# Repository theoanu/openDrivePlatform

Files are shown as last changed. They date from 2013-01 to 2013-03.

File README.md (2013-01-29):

openDrivePlatform
=================

Open-source Hardware/Software motor drive platform from which other more application-specific platforms may be derived.  See below for FUTURE release features.

Connectivity
=================
 - USB (virtual COM port) control
 - I2C control
 - Remote Control (RC) pulse
 - Fast RC pulse control
 - Analog control

Motor types supported
=================
 - Direct Current (DC)
 - Brushless DC (BLDC) - sensored
 - BLDC - sensorless
 - Permanent Magnet Synchronous Motor (PMSM)

Application types supported
=================
 - RC traction applications (wheels, belts, etc.)
 - RC propeller applications
 - Servo applications

Fun features supported
=================
 - Command-line interface using USB
 - Closed-loop Current/torque control
 - Closed-loop Speed control
 - Closed-loop power control
 - Regenerative braking

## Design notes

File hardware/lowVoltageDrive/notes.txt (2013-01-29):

Future revisions:
CAN transceiver: SN65HVD232DR

Current revision:

- In order to increase the gain of the opamp to 10:
 - Change R25, R26 to 10k

- In order to increase the resolution of the ADCs:
 - Change R7, R10, R12, and R14 to 3.3k

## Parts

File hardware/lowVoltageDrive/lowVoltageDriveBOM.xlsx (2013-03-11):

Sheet: lowVoltageDrive
Reference | Value | Manufacturer | Man. Part Number
C1 | 0.47uF 50V | Taiyo Yuden | UMK107B7474KA-TR
C2 | 0.47uF 50V | Taiyo Yuden | UMK107B7474KA-TR
C3 | 1nF 50V | Murata Electronics North America | GRM188R71H102KA01D
C4 | 1nF 50V | Murata Electronics North America | GRM188R71H102KA01D
C5 | 8pF 50V | TDK Corporation | C1608C0G1H080C
C6 | 8pF 50V | TDK Corporation | C1608C0G1H080C
C7 | 1nF 50V | Murata Electronics North America | GRM188R71H102KA01D
C8 | 1nF 50V | Murata Electronics North America | GRM188R71H102KA01D
C9 | 1nF 50V | Murata Electronics North America | GRM188R71H102KA01D
C10 | 0.47uF 50V | Taiyo Yuden | UMK107B7474KA-TR
C11 | 1nF 50V | Murata Electronics North America | GRM188R71H102KA01D
C12 | 0.47uF 50V | Taiyo Yuden | UMK107B7474KA-TR
C13 | 0.47uF 50V | Taiyo Yuden | UMK107B7474KA-TR
C14 | 0.47uF 50V | Taiyo Yuden | UMK107B7474KA-TR
C15 | 0.47uF 50V | Taiyo Yuden | UMK107B7474KA-TR
C16 | 220uF 6.3V | Panasonic Electronic Components | EEE-0JA221WP
C17 | 47uF 25V | Kemet | EEV476M025A9GAA
C18 | 47uF 25V | Kemet | EEV476M025A9GAA
C19 | 0.47uF 50V | Taiyo Yuden | UMK107B7474KA-TR
C20 | 0.47uF 50V | Taiyo Yuden | UMK107B7474KA-TR
C21 | 0.47uF 50V | Taiyo Yuden | UMK107B7474KA-TR
C22 | 0.47uF 50V | Taiyo Yuden | UMK107B7474KA-TR
C23 | 0.47uF 50V | Taiyo Yuden | UMK107B7474KA-TR
C24 | 0.47uF 50V | Taiyo Yuden | UMK107B7474KA-TR
D1 | DIODE | Micro Commercial Inc. | 1N4148WX-TP
D2 | DIODE | Micro Commercial Inc. | 1N4148WX-TP
D3 | DIODE | Micro Commercial Inc. | 1N4148WX-TP
D4 | DIODE | Micro Commercial Inc. | 1N4148WX-TP
J1 | CONN_5X2
J2 | CONN_5
J3 | CONN_5 | TE Connectivity | 5-1775444-5
J4 | CONN_5 | On Shore Technology Inc | OSTTC050162
J5 | CONN_6 | TE Connectivity | 5-1775444-6
Q1 | MOSFET_N_TO220 | Alpha & Omega Semiconductor | AOTF240L
Q2 | MOSFET_N_TO220 | Alpha & Omega Semiconductor | AOTF240L
Q3 | MOSFET_N_TO220 | Alpha & Omega Semiconductor | AOTF240L
Q4 | MOSFET_N_TO220 | Alpha & Omega Semiconductor | AOTF240L
Q5 | MOSFET_N_TO220 | Alpha & Omega Semiconductor | AOTF240L
Q6 | MOSFET_N_TO220 | Alpha & Omega Semiconductor | AOTF240L
R1 | 10.0k | Yageo | RC0603FR-0710KL
R2 | 1.0k | Yageo | RC0603FR-071KL
R3 | 10.0k | Yageo | RC0603FR-0710KL
R4 | 10.0k | Yageo | RC0603FR-0710KL
R5 | 10.0k | Yageo | RC0603FR-0710KL
R6 | 10.0k | Yageo | RC0603FR-0710KL
R7 | 1.5k | Yageo | RC0603FR-071K5L
R8 | 10.0k | Yageo | RC0603FR-0710KL
R9 | 10.0k | Yageo | RC0603FR-0710KL
R10 | 1.5k | Yageo | RC0603FR-071K5L
R11 | 10.0k | Yageo | RC0603FR-0710KL
R12 | 1.5k | Yageo | RC0603FR-071K5L
R13 | 10.0k | Yageo | RC0603FR-0710KL
R14 | 1.5k | Yageo | RC0603FR-071K5L
R15 | 1.0k | Yageo | RC0603FR-071KL
R16 | 1.0k | Yageo | RC0603FR-071KL
R17 | 1.0k | Yageo | RC0603FR-071KL
R18 | 1.0k | Yageo | RC0603FR-071KL
R19 | 1.5k | Yageo | RC0603FR-071K5L
R20 | 1.0k | Yageo | RC0603FR-071KL
R21 | 1.0k | Yageo | RC0603FR-071KL
R22 | 1.0k | Yageo | RC0603FR-071KL
R23 | 10.0k | Yageo | RC0603FR-0710KL
R24 | 1.0k | Yageo | RC0603FR-071KL
R25 | 1.0k | Yageo | RC0603FR-071KL
R26 | 1.0k | Yageo | RC0603FR-071KL
R27 | 33 | Yageo | RC0603JR-0733RL
R28 | 33 | Yageo | RC0603JR-0733RL
R29 | 33 | Yageo | RC0603JR-0733RL
R30 | 33 | Yageo | RC0603JR-0733RL
R31 | 33 | Yageo | RC0603JR-0733RL
R32 | 33 | Yageo | RC0603JR-0733RL
R33 | 10.0k | Yageo | RC0603FR-0710KL
R34 | 10.0k | Yageo | RC0603FR-0710KL
R35 | 1.0k | Yageo | RC0603FR-071KL
R36 | 1.0k | Yageo | RC0603FR-071KL
R37 | 0.01 | Vishay Dale | WSH2818R0100FEA
U1 | VREG_4 | ON Semiconductor | NCP1117LPST33T3G
U2 | STM32F103XX-48 | STMicroelectronics | STM32F103C4T6A
U3 | QUAD_OPAMP | STMicroelectronics | TS974IDT
U4 | MOSFET_DRIVER | International Rectifier | IR2301SPBF
U5 | MOSFET_DRIVER | International Rectifier | IR2301SPBF
U6 | MOSFET_DRIVER | International Rectifier | IR2301SPBF
X1 | CRYSTAL | NDK | NX5032GA 8MHZ AT-W

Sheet: Sheet1
Item | Qty | Reference | Value | Manufacturer | Man. Part Number | 10pc Price/part | 10pc Price | 1kpc Price/part | 1kpc Price
1 | 13 | C1,C2,C10,C12,C13,C14,C15,C19,C20,C21,C22,C23,C24 | 0.47uF 50V | Taiyo Yuden | UMK107B7474KA-TR | $0.0640 | $0.8320 | $0.0152 | $0.1976
2 | 6 | C3,C4,C7,C8,C9,C11 | 1nF 50V | Murata Electronics North America | GRM188R71H102KA01D | $0.0110 | $0.0660 | $0.0039 | $0.0235
3 | 2 | C5,C6 | 8pF 50V | TDK Corporation | C1608C0G1H080C | $0.0420 | $0.0840 | $0.0105 | $0.0210
4 | 1 | C16 | 220uF 6.3V | Panasonic Electronic Components | EEE-0JA221WP | $0.5500 | $0.5500 | $0.0992 | $0.0992
5 | 2 | C17,C18 | 47uF 25V | Kemet | EEV476M025A9GAA | $0.3050 | $0.6100 | $0.0783 | $0.1566
6 | 4 | D1,D2,D3,D4 | DIODE | Micro Commercial Inc. | 1N4148WX-TP | $0.1320 | $0.5280 | $0.0286 | $0.1144
7 | 1 | J1 | CONN_5X2 |  |  |  | $0.0000 |  | $0.0000
8 | 1 | J2 | CONN_5 |  |  |  | $0.0000 |  | $0.0000
9 | 1 | J3 | CONN_5 | TE Connectivity | 5-1775444-5 | $0.5710 | $0.5710 | $0.2857 | $0.2857
10 | 1 | J4 | CONN_5 | On Shore Technology Inc | OSTTC050162 | $0.6550 | $0.6550 | $0.4112 | $0.4112
11 | 1 | J5 | CONN_6 | TE Connectivity | 5-1775444-6 | $0.6820 | $0.6820 | $0.3411 | $0.3411
12 | 6 | Q1,Q2,Q3,Q4,Q5,Q6 | MOSFET_N_TO220 | Alpha & Omega Semiconductor | AOTF240L | $1.6200 | $9.7200 | $0.8424 | $5.0544
13 | 12 | R1,R3,R4,R5,R6,R8,R9,R11,R13,R23,R33,R34 | 10.0k | Yageo | RC0603FR-0710KL | $0.0063 | $0.0756 | $0.0015 | $0.0179
14 | 13 | R2,R15,R16,R17,R18,R20,R21,R22,R24,R25,R26,R35,R36 | 1.0k | Yageo | RC0603FR-071KL | $0.0063 | $0.0819 | $0.0015 | $0.0194
15 | 5 | R7,R10,R12,R14,R19 | 1.5k | Yageo | RC0603FR-071K5L | $0.0140 | $0.0700 | $0.0017 | $0.0086
16 | 6 | R27,R28,R29,R30,R31,R32 | 33 | Yageo | RC0603JR-0733RL | $0.0100 | $0.0600 | $0.0013 | $0.0079
17 | 1 | R37 | 0.01 | Vishay Dale | WSH2818R0100FEA | $0.4040 | $0.4040 | $0.1900 | $0.1900
18 | 1 | U1 | VREG_4 | ON Semiconductor | NCP1117LPST33T3G | $0.3930 | $0.3930 | $0.1384 | $0.1384
19 | 1 | U2 | STM32F103XX-48 | STMicroelectronics | STM32F103C4T6A | $4.5930 | $4.5930 | $2.5718 | $2.5718
20 | 1 | U3 | QUAD_OPAMP | STMicroelectronics | TS974IDT | $1.2730 | $1.2730 | $0.6185 | $0.6185
21 | 3 | U4,U5,U6 | MOSFET_DRIVER | Fairchild Semiconductor | FAN7842MX | $0.9648 | $2.8944 | $0.4690 | $1.4070
22 | 1 | X1 | CRYSTAL | NDK | NX5032GA 8MHZ AT-W | $1.4740 | $1.4740 | $0.6350 | $0.6350
23 | 1 | PCB, custom | - | SlightlyNybbled | - | $15.0000 | $15.0000 | $1.0000 | $1.0000
 |  |  |  |  | Price for materials |  | $40.6169 |  | $13.3190
 |  |  |  |  | Price for turn-key |  | $4.0617 |  | $1.3319
 |  |  |  |  | Price for assembly |  | $10.0000 |  | $1.5000
 |  |  |  |  | Price each |  | $54.6786 |  | $16.1509

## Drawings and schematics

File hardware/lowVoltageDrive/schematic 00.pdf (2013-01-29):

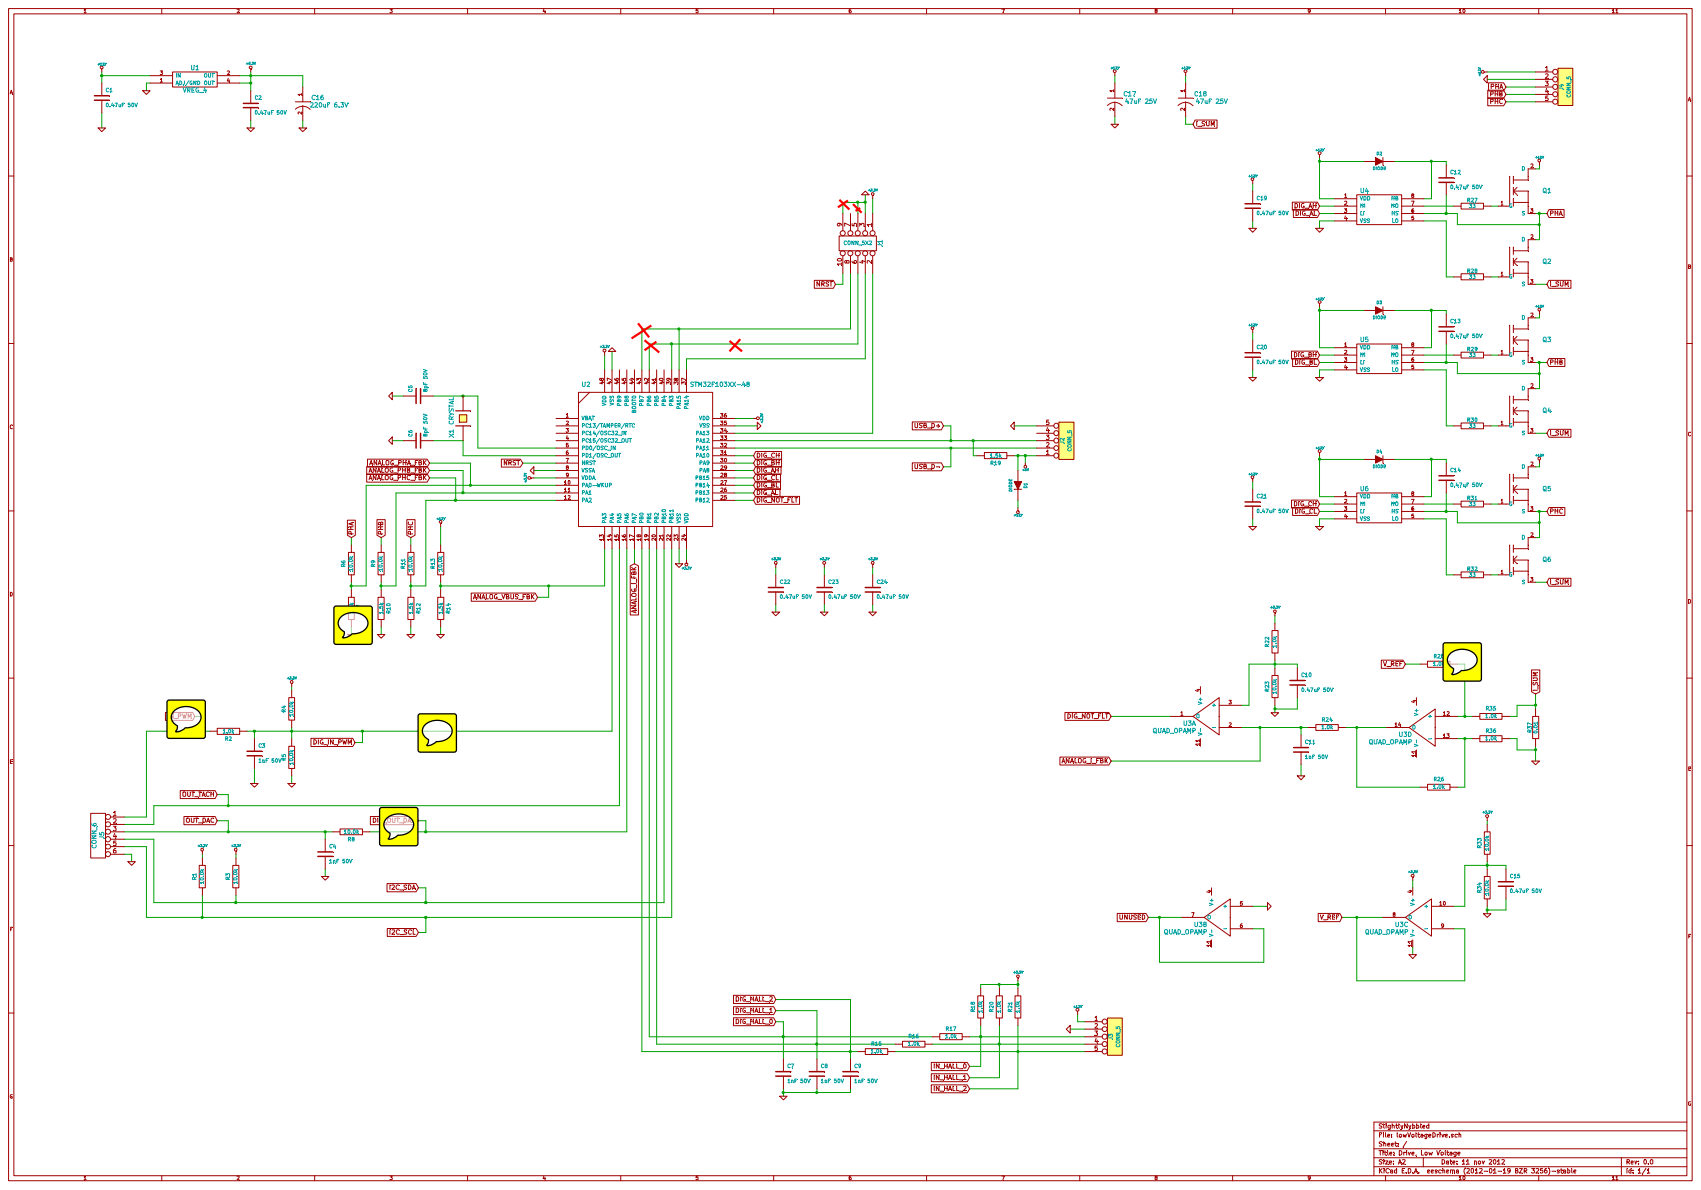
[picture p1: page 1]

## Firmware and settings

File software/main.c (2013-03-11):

/**************************************************
 * This file is Public Domain
 *
 * This file is distributed in the hope that it will
 *	be useful, but WITHOUT ANY WARRANTY; without
 *	even the implied warranty of MERCHANTABILITY
 *	or FITNESS FOR A PARTICULAR PURPOSE.
*************************************************/
#include "hw_config.h"
#include "usb_lib.h"
#include "usb_desc.h"
#include "usb_pwr.h"

#include "gpio.h"
#include "osc.h"
#include "milliSecTimer.h"
#include "motor.h"
#include "rcPwm.h"
#include "adc.h"

#include "stdio.h"
double f;

void initDio(void);

int
main(void)
{
	// Initialize oscillator
	OSC_initClock();

	// Initialize the milliSecond timer
	MSTMR_initMilliSecTimer();

	// Initialize timing variables
	uint32_t now = MSTMR_getMilliSeconds();
	uint32_t lastExecutionTime = now;

	// Initialize General-purpose I/O (when code is more complete,
	//	this will be done in the individual software modules
	initDio();

	// Initialize ADC
	ADC_initAdc();

	// Initialize RC PWM module
	RCPWM_initRcPwm();

	// Initialize motor
	MOT_defineMotorType(MOT_BLDC);

	// init USB
	Set_USBClock();
	USB_Interrupts_Config();
	USB_Init();

	// Initialize UART/CLI

	// Initialize bootloader

	// Infinite loop
    while(1)
    {
    	// Use the millisecond timer to time all operations within the main loop
    	now = MSTMR_getMilliSeconds();

    	// Error checking to ensure that the lastExecutionTime
    	//	is not somehow much greater than the now variable
    	//	through some unforeseen event
    	if(lastExecutionTime > now)
    	{
    		lastExecutionTime = now;
    	}

    	// Everything in this IF statement will be executed one time every millisecond
    	if(now > lastExecutionTime)
    	{
    		lastExecutionTime = now;

         	// Get requested duty cycle from rcPwm/USB/UART/I2C
    		uint32_t speedDemand = RCPWM_getSpeedDemand();
    		if(speedDemand > 15000)
    			speedDemand = 15000;

        	// Pass requested duty cycle to the motor
    		MOT_commandDirection(MOT_POS);
    		MOT_commandDutyCycle(speedDemand);
    	} // END if statement
    } //END while loop

    return 0;
}

void
initDio(void)
{
	// Setup analog input pins
	// Analog input pins are not remapped
	GPIO_pinSetup(GPIO_PORT_A, 0, GPIO_INPUT_ANALOG);	// PHA FBK
	GPIO_pinSetup(GPIO_PORT_A, 1, GPIO_INPUT_ANALOG);	// PHB FBK
	GPIO_pinSetup(GPIO_PORT_A, 2, GPIO_INPUT_ANALOG);	// PHC FBK
	GPIO_pinSetup(GPIO_PORT_A, 3, GPIO_INPUT_ANALOG);	// Bus Voltage
	GPIO_pinSetup(GPIO_PORT_A, 7, GPIO_INPUT_ANALOG);	// Bus Current
	GPIO_pinSetup(GPIO_PORT_A, 4, GPIO_INPUT_ANALOG);	// Speed control

	// Setup output tach pin
	GPIO_pinSetup(GPIO_PORT_A, 5, GPIO_OUTPUT_PP);

	// Setup hall sensors
	GPIO_pinSetup(GPIO_PORT_B, 0, GPIO_FLOATING_INPUT);
	GPIO_pinSetup(GPIO_PORT_B, 1, GPIO_FLOATING_INPUT);
	GPIO_pinSetup(GPIO_PORT_B, 2, GPIO_FLOATING_INPUT);

	// Setup current fault as a pull-up to eliminate external pull-ups
	// Overcurrent sensing pin is not remapped
	GPIO_pinSetup(GPIO_PORT_A, 7, GPIO_INPUT_PU_OR_PD);	// Overcurrent

	return;
} // END initDio()

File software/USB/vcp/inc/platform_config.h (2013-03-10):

/**
  ******************************************************************************
  * @file    platform_config.h
  * @author  MCD Application Team
  * @version V3.4.0
  * @date    29-June-2012
  * @brief   Evaluation board specific configuration file.
  ******************************************************************************
  * @attention
  *
  * <h2><center>&copy; COPYRIGHT 2012 STMicroelectronics</center></h2>
  *
  * Licensed under MCD-ST Liberty SW License Agreement V2, (the "License");
  * You may not use this file except in compliance with the License.
  * You may obtain a copy of the License at:
  *
  *        http://www.st.com/software_license_agreement_liberty_v2
  *
  * Unless required by applicable law or agreed to in writing, software 
  * distributed under the License is distributed on an "AS IS" BASIS, 
  * WITHOUT WARRANTIES OR CONDITIONS OF ANY KIND, either express or implied.
  * See the License for the specific language governing permissions and
  * limitations under the License.
  *
  ******************************************************************************
  */


/* Define to prevent recursive inclusion -------------------------------------*/
#ifndef __PLATFORM_CONFIG_H
#define __PLATFORM_CONFIG_H

/* Includes ------------------------------------------------------------------*/
#if defined(STM32F10X_LD)
 #include "stm32f10x.h"

#define EVAL_COM1                        USART1
#define EVAL_COM1_CLK                    RCC_APB2Periph_USART1
#define EVAL_COM1_TX_PIN                 GPIO_Pin_9
#define EVAL_COM1_TX_GPIO_PORT           GPIOA
#define EVAL_COM1_TX_GPIO_CLK            RCC_APB2Periph_GPIOA
#define EVAL_COM1_RX_PIN                 GPIO_Pin_10
#define EVAL_COM1_RX_GPIO_PORT           GPIOA
#define EVAL_COM1_RX_GPIO_CLK            RCC_APB2Periph_GPIOA
#define EVAL_COM1_IRQn                   USART1_IRQn

typedef enum 
{
  COM1 = 0,
  COM2 = 1
} COM_TypeDef;

void STM_EVAL_COMInit(COM_TypeDef COM, USART_InitTypeDef* USART_InitStruct);

#else
#if defined(STM32L1XX_MD) || defined(STM32L1XX_HD)|| defined(STM32L1XX_MD_PLUS)
 #include "stm32l1xx.h"
 #if defined (USE_STM32L152_EVAL)
  #include "stm32l152_eval.h"
 #elif defined (USE_STM32L152D_EVAL)
  #include "stm32l152d_eval.h"
 #else
  #error "Missing define: USE_STM32L152_EVAL or USE_STM32L152D_EVAL"
 #endif /* USE_STM32L152_EVAL */
#elif defined (STM32F10X_MD) || defined (STM32F10X_HD) || defined (STM32F10X_XL) || defined (STM32F10X_CL)
 #include "stm32f10x.h"
 #if defined (USE_STM3210B_EVAL)
  #include "stm3210b_eval.h"
 #elif defined (USE_STM3210E_EVAL)
  #include "stm3210e_eval.h"
 #elif defined (USE_STM3210C_EVAL)
  #include "stm3210c_eval.h"
  #include "stm3210c_eval_ioe.h"
 #else
  #error "Missing define: USE_STM3210B_EVAL, USE_STM3210E_EVAL or USE_STM3210C_EVAL"
 #endif /* USE_STM3210B_EVAL */
#endif
#endif

/* Exported types ------------------------------------------------------------*/
/* Exported constants --------------------------------------------------------*/
/* Uncomment the line corresponding to the STMicroelectronics evaluation board
   used to run the example */
#if !defined (USE_STM3210B_EVAL) &&  !defined (USE_STM3210E_EVAL)  &&  !defined (USE_STM3210C_EVAL)  &&  !defined (USE_STM32L152_EVAL) &&  !defined (USE_STM32L152D_EVAL)
 //#define USE_STM3210B_EVAL
 //#define USE_STM3210E_EVAL
 //#define USE_STM3210C_EVAL
 //#define USE_STM32L152_EVAL
//#define USE_STM32L152D_EVAL
#endif


/* Define the STM32F10x hardware depending on the used evaluation board */
#ifdef STM32F10X_LD
  #define USB_DISCONNECT                      0  
  #define USB_DISCONNECT_PIN                  0
  #define RCC_APB2Periph_GPIO_DISCONNECT      0
  #define EVAL_COM1_IRQHandler                USART2_IRQHandler 
#endif

#ifdef USE_STM3210B_EVAL
  #define USB_DISCONNECT                      GPIOD  
  #define USB_DISCONNECT_PIN                  GPIO_Pin_9
  #define RCC_APB2Periph_GPIO_DISCONNECT      RCC_APB2Periph_GPIOD
  #define EVAL_COM1_IRQHandler                USART1_IRQHandler 

#elif defined (USE_STM3210E_EVAL)
  #define USB_DISCONNECT                      GPIOB  
  #define USB_DISCONNECT_PIN                  GPIO_Pin_14
  #define RCC_APB2Periph_GPIO_DISCONNECT      RCC_APB2Periph_GPIOB
  #define EVAL_COM1_IRQHandler                USART1_IRQHandler 

#elif defined (USE_STM3210C_EVAL)
  #define USB_DISCONNECT                      0  
  #define USB_DISCONNECT_PIN                  0
  #define RCC_APB2Periph_GPIO_DISCONNECT      0
  #define EVAL_COM1_IRQHandler                USART2_IRQHandler
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

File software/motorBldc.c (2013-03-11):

/**************************************************
 * This file is Public Domain
 *
 * This file is distributed in the hope that it will
 *	be useful, but WITHOUT ANY WARRANTY; without
 *	even the implied warranty of MERCHANTABILITY
 *	or FITNESS FOR A PARTICULAR PURPOSE.
*************************************************/
#include "misc.h"
#include "motorBldc.h"
#include "mpwm.h"
#include "gpio.h"
#include "adc.h"
#include "milliSecTimer.h"

#define NULL	0

/* Global variables */
typedef struct
{
	volatile uint8_t state;
	volatile int8_t sector;
	volatile uint16_t dutyCycle;
	volatile uint32_t startTimeAbs;
	volatile uint32_t startCommutationTimeAbs;
	volatile uint32_t lockUntilTimeAbs;
	volatile uint16_t phaseA, phaseB, phaseC;
	volatile uint16_t *dormantPhasePtr;
	_BLDC_motorDirection direction;

	_BLDC_sensor sensor;

	uint8_t hallToSector[8];
} _bldc_motor;

typedef struct{
	bool direction;
	uint16_t dutyCycle;
}_bldc_motor_command;

volatile _bldc_motor BLDC_motor;
_bldc_motor_command BLDC_command;

// Used internally to motor.c, "private"
void BLDC_commutate(void);
void BLDC_initPositionSensors(void);
void BLDC_determineSector(void);
void BLDC_adcInterrupt(void);

/* This is a complete table that lists all of the possible translations
 * from hall sensor inputs to sectors. */
const uint8_t hallToSector[12][8] = {	{6,1,3,2,5,0,4,6},
										{6,0,2,1,4,5,3,6},
										{6,5,1,0,3,4,2,6},
										{6,4,0,5,2,3,1,6},
										{6,3,5,4,1,2,0,6},
										{6,2,4,3,0,1,5,6},
										{6,4,2,3,0,5,1,6},
										{6,3,1,2,5,4,0,6},
										{6,2,0,1,4,3,5,6},
										{6,1,5,0,3,2,4,6},
										{6,0,4,5,2,1,3,6},
										{6,5,3,4,1,0,2,6}};

/* This specifies which line is to be used from the hallToSector table */
uint8_t hallTableUtilized = 0;

/***************************************************************
 * Function:	void BLDC_initMotor(void)
 *
 * Purpose:		This function is called by higher-level software in order
 * 					to initialize the motor in preparation for operation.
 *
 * Parameters:	none
 *
 * Returns:		none
 *
 * Globals affected:	none
 **************************************************************/
void
BLDC_initMotor(void)
{
	MPWM_initMotorPwm();
	MPWM_setMotorPwmFreq(16000);

	BLDC_stopMotor();
	BLDC_commandDirection(BLDC_POS);

	BLDC_initPositionSensors();

	// Assign the ADC1 Interrupt to the BLDC_adcInterrupt() function
	//	and enable the interrupt.  Whenever an ADC1 interrupt occurs,
	//	it will execute the BLDC_adcInterrupt() code from this file.
	ADC_initAdc1Interrupt(&BLDC_adcInterrupt);

	return;
} // END BLDC_initMotor()

/***************************************************************
 * Function:	void BLDC_initPositionSensors(void)
 *
 * Purpose:		This function will identify the type of sensors utilized (if any
 * 				and will take any action necessary to initialize the sensor(s)
 *
 * Parameters:	none
 *
 * Returns:		none
 *
 * Globals affected:	none
 **************************************************************/
void
BLDC_initPositionSensors(void)
{
	unsigned int hallValue = 0;

	/* Hall sensors to inputs */
	GPIO_pinSetup(GPIO_PORT_B, 0, GPIO_FLOATING_INPUT);
	GPIO_pinSetup(GPIO_PORT_B, 1, GPIO_FLOATING_INPUT);
	GPIO_pinSetup(GPIO_PORT_B, 2, GPIO_FLOATING_INPUT);

	/* Read the current hall sensor values */
	hallValue += (uint16_t)GPIO_readInput(GPIO_PORT_B, 0);
	hallValue += (uint16_t)GPIO_readInput(GPIO_PORT_B, 1) << 1;
	hallValue += (uint16_t)GPIO_readInput(GPIO_PORT_B, 2) << 2;

	/* If the hall sensor values is valid, then
	 * hall sensors are utilized for sensors */
	if((hallValue != 0) && (hallValue != 7))
	{
		BLDC_motor.sensor = BLDC_HALL;

		// Load the table to be used from program memory
		for(uint8_t i = 0; i < 8; i++)
		{
			BLDC_motor.hallToSector[i] = hallToSector[hallTableUtilized][i];
		}
	}

	return;
} // END BLDC_initPositionSensors

/***************************************************************
 * Function:	void BLDC_startMotor(void)
 *
 * Purpose:		This function is called by higher-level software
 * 					when motor rotation should begin
 *
 * Parameters:	none
 *
 * Returns:		none
 *
 * Globals affected:	BLDC_motor.sector, BLDC_motor.state
 **************************************************************/
void
BLDC_startMotor(void)
{
	// Only allow this routine to execute if
	//	the motor is in the STOPPED state
	if(BLDC_motor.state == BLDC_STOPPED)
	{
		BLDC_motor.sector = 0;
		BLDC_motor.state = BLDC_STARTING;

		BLDC_motor.startTimeAbs = MSTMR_getMilliSeconds();

		BLDC_motor.dutyCycle = BLDC_MIN_DUTY_CYCLE;
		BLDC_motor.direction = BLDC_command.direction;

		BLDC_determineSector();
		BLDC_commutate();
	}

	return;
} // END BLDC_startMotor()

/***************************************************************
 * Function:	void BLDC_stopMotor(void)
 *
 * Purpose:		This function is called by higher-level software
 * 					when motor rotation should cease
 *
 * Parameters:	none
 *
 * Returns:		none
 *
 * Globals affected:	BLDC_motor.sector, BLDC_motor.state
 **************************************************************/
void
BLDC_stopMotor(void)
{
	// Place each phase in the DORMANT state
	MPWM_setPhaseDutyCycle(MPWM_PH_A, MPWM_DORMANT, 0);
	MPWM_setPhaseDutyCycle(MPWM_PH_B, MPWM_DORMANT, 0);
	MPWM_setPhaseDutyCycle(MPWM_PH_C, MPWM_DORMANT, 0);

	// Place the motor in the STOPPED state
	BLDC_motor.state = BLDC_STOPPED;

	return;
} // END BLDC_stopMotor()

/***************************************************************
 * Function:	void BLDC_determineSector(void)
 *
 * Purpose:		This function will return the motor sector
 *
 * Parameters:	none
 *
 * Returns:		none
 *
 * Globals affected:	BLDC_motor.sensorState, BLDC_motor.sector
 **************************************************************/
void
BLDC_determineSector(void)
{
	uint8_t sector;

	switch(BLDC_motor.sensor)
	{
		case BLDC_SENSORLESS:
		{
			break;
		}

		case BLDC_HALL:
		{
			unsigned int hallValue = 0;

			hallValue += (uint16_t)GPIO_readInput(GPIO_PORT_B, 0);
			hallValue += (uint16_t)GPIO_readInput(GPIO_PORT_B, 1) << 1;
			hallValue += (uint16_t)GPIO_readInput(GPIO_PORT_B, 2) << 2;

			/* Uses a lookup table to determine the current
			 * sector based on the current hall value */
			BLDC_motor.sector = sector = BLDC_motor.hallToSector[hallValue];

			break;
		}

		default:
		{
			break;
		}
	}

	return;
} // END BLDC_determineSector
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

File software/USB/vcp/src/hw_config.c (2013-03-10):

/**
  ******************************************************************************
  * @file    hw_config.c
  * @author  MCD Application Team
  * @version V3.4.0
  * @date    29-June-2012
  * @brief   Hardware Configuration & Setup
  ******************************************************************************
  * @attention
  *
  * <h2><center>&copy; COPYRIGHT 2012 STMicroelectronics</center></h2>
  *
  * Licensed under MCD-ST Liberty SW License Agreement V2, (the "License");
  * You may not use this file except in compliance with the License.
  * You may obtain a copy of the License at:
  *
  *        http://www.st.com/software_license_agreement_liberty_v2
  *
  * Unless required by applicable law or agreed to in writing, software 
  * distributed under the License is distributed on an "AS IS" BASIS, 
  * WITHOUT WARRANTIES OR CONDITIONS OF ANY KIND, either express or implied.
  * See the License for the specific language governing permissions and
  * limitations under the License.
  *
  ******************************************************************************
  */


/* Includes ------------------------------------------------------------------*/

#include "stm32_it.h"
#include "usb_lib.h"
#include "usb_prop.h"
#include "usb_desc.h"
#include "hw_config.h"
#include "usb_pwr.h"
#include "buffer.h"

/* Private typedef -----------------------------------------------------------*/
/* Private define ------------------------------------------------------------*/
/* Private macro -------------------------------------------------------------*/
/* Private variables ---------------------------------------------------------*/
ErrorStatus HSEStartUpStatus;
USART_InitTypeDef USART_InitStructure;
/*
uint8_t  USART_Rx_Buffer [USART_RX_DATA_SIZE]; 
uint32_t USART_Rx_ptr_in = 0;
uint32_t USART_Rx_ptr_out = 0;
uint32_t USART_Rx_length  = 0;
*/
EXTERN_BUFFER(USB_RX, 256);
EXTERN_BUFFER(USB_TX, 256);

uint8_t  USB_Tx_State = 0;
static void IntToUnicode (uint32_t value , uint8_t *pbuf , uint8_t len);
/* Extern variables ----------------------------------------------------------*/

extern LINE_CODING linecoding;

/* Private function prototypes -----------------------------------------------*/
/* Private functions ---------------------------------------------------------*/
/*******************************************************************************
* Function Name  : Set_System
* Description    : Configures Main system clocks & power
* Input          : None.
* Return         : None.
*******************************************************************************/
void Set_System(void)
{
#if !defined(STM32F10X_CL) && !defined(STM32L1XX_MD) && !defined(STM32L1XX_HD) && !defined(STM32L1XX_MD_PLUS)
  GPIO_InitTypeDef GPIO_InitStructure;
#endif /* STM32F10X_CL && STM32L1XX_XD */  

#if defined(USB_USE_EXTERNAL_PULLUP)
  GPIO_InitTypeDef  GPIO_InitStructure;
#endif /* USB_USE_EXTERNAL_PULLUP */ 
  
  /*!< At this stage the microcontroller clock setting is already configured, 
       this is done through SystemInit() function which is called from startup
       file (startup_stm32f10x_xx.s) before to branch to application main.
       To reconfigure the default setting of SystemInit() function, refer to
       system_stm32f10x.c file
     */   
#if defined(STM32L1XX_MD) || defined(STM32L1XX_HD)|| defined(STM32L1XX_MD_PLUS)
  /* Enable the SYSCFG module clock */
  RCC_APB2PeriphClockCmd(RCC_APB2Periph_SYSCFG, ENABLE);
#endif /* STM32L1XX_XD */ 
   
#if !defined(STM32F10X_CL) && !defined(STM32L1XX_MD) && !defined(STM32L1XX_HD) && !defined(STM32L1XX_MD_PLUS)
  /* Enable USB_DISCONNECT GPIO clock */
  RCC_APB2PeriphClockCmd(RCC_APB2Periph_GPIO_DISCONNECT, ENABLE);

  /* Configure USB pull-up pin */
  GPIO_InitStructure.GPIO_Pin = USB_DISCONNECT_PIN;
  GPIO_InitStructure.GPIO_Speed = GPIO_Speed_50MHz;
  GPIO_InitStructure.GPIO_Mode = GPIO_Mode_Out_OD;
  GPIO_Init(USB_DISCONNECT, &GPIO_InitStructure);
#endif /* STM32F10X_CL && STM32L1XX_XD */
   
#if defined(USB_USE_EXTERNAL_PULLUP)
  /* Enable the USB disconnect GPIO clock */
  RCC_AHBPeriphClockCmd(RCC_AHBPeriph_GPIO_DISCONNECT, ENABLE);

  /* USB_DISCONNECT used as USB pull-up */
  GPIO_InitStructure.GPIO_Pin = USB_DISCONNECT_PIN;
  GPIO_InitStructure.GPIO_Mode = GPIO_Mode_OUT;
  GPIO_InitStructure.GPIO_Speed = GPIO_Speed_2MHz;
  GPIO_InitStructure.GPIO_OType = GPIO_OType_PP;
  GPIO_InitStructure.GPIO_PuPd = GPIO_PuPd_NOPULL;
  GPIO_Init(USB_DISCONNECT, &GPIO_InitStructure);  
#endif /* USB_USE_EXTERNAL_PULLUP */  
}
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

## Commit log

2013-01-29 RC Pulse Width test code using Arduino Uno
2013-01-29 PCBA hardware files added
    [lowVoltageDrive.brd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]
2013-01-30 ADC interrupt refinement
    Added method to initialize and ADC1 or ADC2 interrupt easily. The
    low-level code also calls the function address from high-level code that
    is assigned during the interrupt initialization. This makes it easier
    to write portable code at the high level.
    [lowVoltageDriveBOM.xlsx]
2013-01-30 Added comments to ADC and BLDC files
2013-02-05 Motor rotates in open-loop mode, either direction
    Made some structural changes throughout code to get rotation.
2013-03-10 USB support added
    - added basic USB support (echo back the characters received)
    - removed semihosting (now printf is redirected to USB)
    - added .gitignore

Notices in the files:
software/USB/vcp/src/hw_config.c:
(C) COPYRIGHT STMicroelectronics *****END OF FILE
